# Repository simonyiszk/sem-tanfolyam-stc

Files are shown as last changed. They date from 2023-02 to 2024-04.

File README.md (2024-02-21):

# sem-tanfolyam-stc #

STC8G1K08 mikrovezérlős fejlesztőpanel a Schönherz Elektronikai Műhely alapozó tanfolyamához (2023-tól).
A projekt tartalmaz a devboardon kívül egy analóg hőmérővel, 7-szegmens kijelzőkkel, LED-ekkel, valamint gombokkal felszerelt alappanelt is, ezt tervezzük meg és készítjük el a tanfolyam során.

### Fejlesztőpanel fícsörök: ###
* Breadboard-ba illeszthető
* Feliratozott lábak
* USB-C csatlakozó
* Integrált programozó és táp-glitchelő áramkör
* Táp- és kommunikáció visszajelző LED-ek
* RESET gomb

[A mikrovezérlő adatlapja itt található.](https://www.stcmcudata.com/STC8F-DATASHEET/STC8G-EN.pdf)

tanfolyam-stc

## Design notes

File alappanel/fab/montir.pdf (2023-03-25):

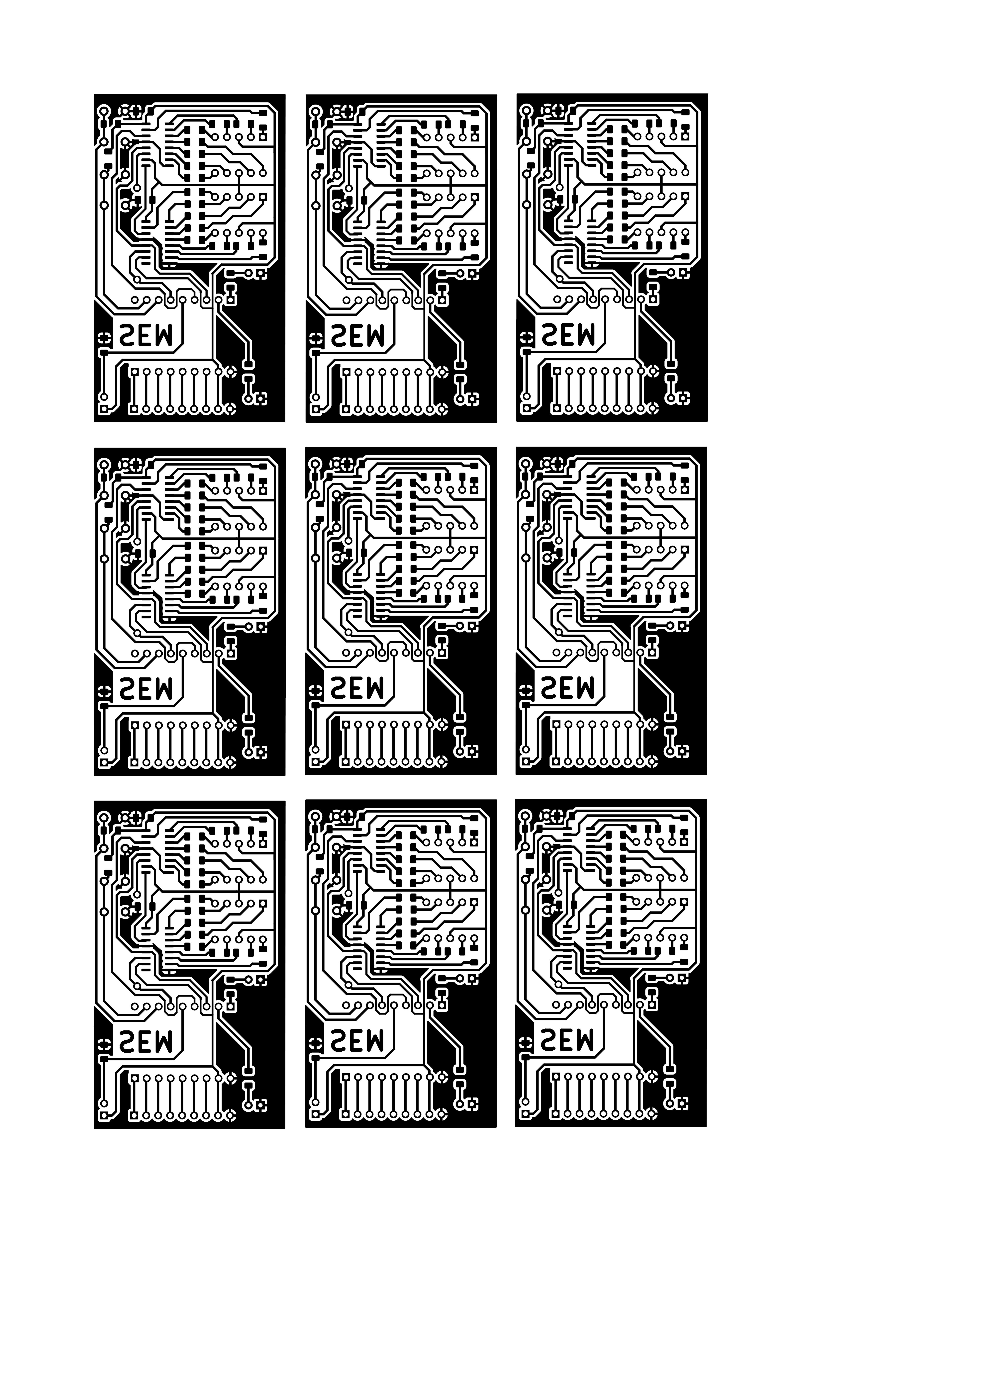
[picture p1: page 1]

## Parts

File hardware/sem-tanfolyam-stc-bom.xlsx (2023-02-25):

Comment | Designator | Footprint | JLCPCB Part #（optional）
100nF | C1, C3 | Capacitor_SMD:C_0603_1608Metric | C14663
1uF | C2, C4 | Capacitor_SMD:C_0603_1608Metric | C15849
LL4148 | D1, D2 | Diode_SMD:D_MiniMELF | C9808
Red | D3 | LED_SMD:LED_0603_1608Metric | C2286
Yellow | D4 | LED_SMD:LED_0603_1608Metric | C72038
1A | F1 | Fuse:Fuse_1206_3216Metric | C883131
Conn_01x09_Male | J1, J2 | Connector_PinHeader_2.54mm:PinHeader_1x09_P2.54mm_Vertical
USB_C_Receptacle_USB2.0 | J3 | Connector_USB:USB_C_Receptacle_G-Switch_GT-USB-7010ASV | C2765186
MMBT5401 | Q1 | Package_TO_SOT_SMD:SOT-23 | C8326
AO3401 | Q2 | Package_TO_SOT_SMD:SOT-23 | C15127
220 | R1, R6 | Resistor_SMD:R_0603_1608Metric | C8218
10k | R2, R3, R4, R5, R7 | Resistor_SMD:R_0603_1608Metric | C25804
5k1 | R8, R9 | Resistor_SMD:R_0603_1608Metric | C23186
1k | R10, R11 | Resistor_SMD:R_0603_1608Metric | C21190
SW_Push | SW1 | Button_Switch_SMD:SW_Push_1P1T_NO_6x6mm_H9.5mm | C318884
CH340E | U1 | Package_SO:MSOP-10_3x3mm_P0.5mm | C99652
STC8G1K08 | U2 | Package_SO:TSSOP-20_4.4x6.5mm_P0.65mm | C521757

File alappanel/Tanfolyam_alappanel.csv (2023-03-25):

Source: | /home/pali/Documents/BME/SEM/Tanfolyam/Tanfolyam-STC/alappanel/Tanfolyam_alappanel.kicad_sch
Date: | 2023. márc. 25., szombat, 10:59:26 CET
Tool: | Eeschema 7.0.1-3b83917a11~172~ubuntu22.04.1
Generator: | /usr/share/kicad/plugins/bom_csv_grouped_by_value.py
Component Count: | 35
Collated Components:
Item | Qty | Reference(s) | Value | LibPart | Footprint | Datasheet | DNP
1 | 2 | C1, C2 | 100n | Device:C | Capacitor_SMD:C_1206_3216Metric_Pad1.33x1.80mm_HandSolder | ~
2 | 2 | D1, D2 | RED | Device:LED_Filled | LED_THT:LED_D5.0mm | ~
3 | 2 | J1, J2 | Connector | Connector:Conn_01x09_Socket | Connector_PinSocket_2.54mm:PinSocket_1x09_P2.54mm_Vertical | ~
4 | 1 | J3 | Connector | Connector:Conn_01x09_Socket | Connector_PinHeader_2.54mm:PinHeader_1x09_P2.54mm_Vertical | ~
5 | 1 | R1 | R | Device:R | Resistor_SMD:R_1206_3216Metric_Pad1.30x1.75mm_HandSolder | ~
6 | 2 | R2, R3 | 10k | Device:R | Resistor_SMD:R_1206_3216Metric_Pad1.30x1.75mm_HandSolder | ~
7 | 18 | R4, R5, R6, R7, R8, R9, R10, R11, R12, R13, R14, R15, R16, R17, R18, R19, R20, R21 | 1k | Device:R | Resistor_SMD:R_1206_3216Metric_Pad1.30x1.75mm_HandSolder | ~
8 | 2 | SW1, SW2 | SW_Push | Switch:SW_Push | Button_Switch_THT:SW_PUSH_6mm | ~
9 | 1 | TH1 | NTC | Device:Thermistor | Connector_PinHeader_2.54mm:PinHeader_1x02_P2.54mm_Vertical | ~
10 | 2 | U1, U2 | 74HC595 | 74xx:74HC595 | Package_SO:SOIC-16_3.9x9.9mm_P1.27mm | http://www.ti.com/lit/ds/symlink/sn74hc595.pdf
11 | 2 | U3, U4 | SA39-11SRWA | Display_Character:SA39-11SRWA | Display_7Segment:Sx39-1xxxxx | http://www.kingbrightusa.com/images/catalog/SPEC/sa39-11srwa.pdf

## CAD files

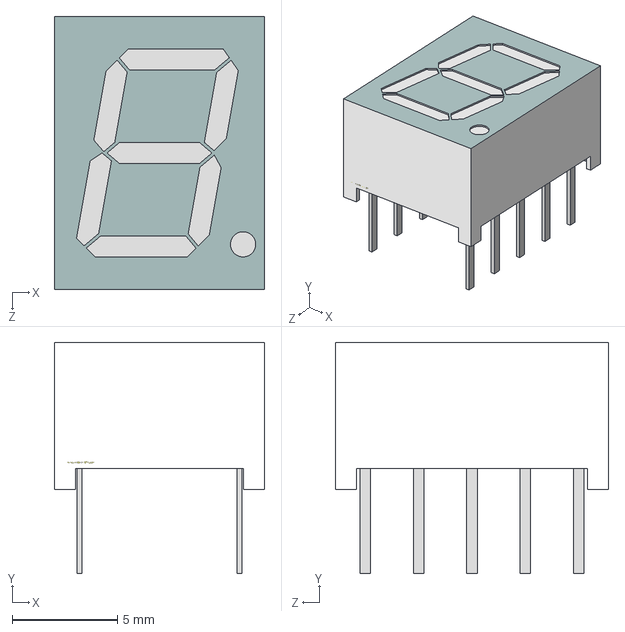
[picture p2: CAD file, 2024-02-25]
alappanel/SA39-11.STEP
10.0 x 11.0 x 13.0 mm

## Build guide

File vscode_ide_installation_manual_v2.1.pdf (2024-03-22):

## Visual Studio Code-alapú fejlesztői környezet telepítési útmutatója a

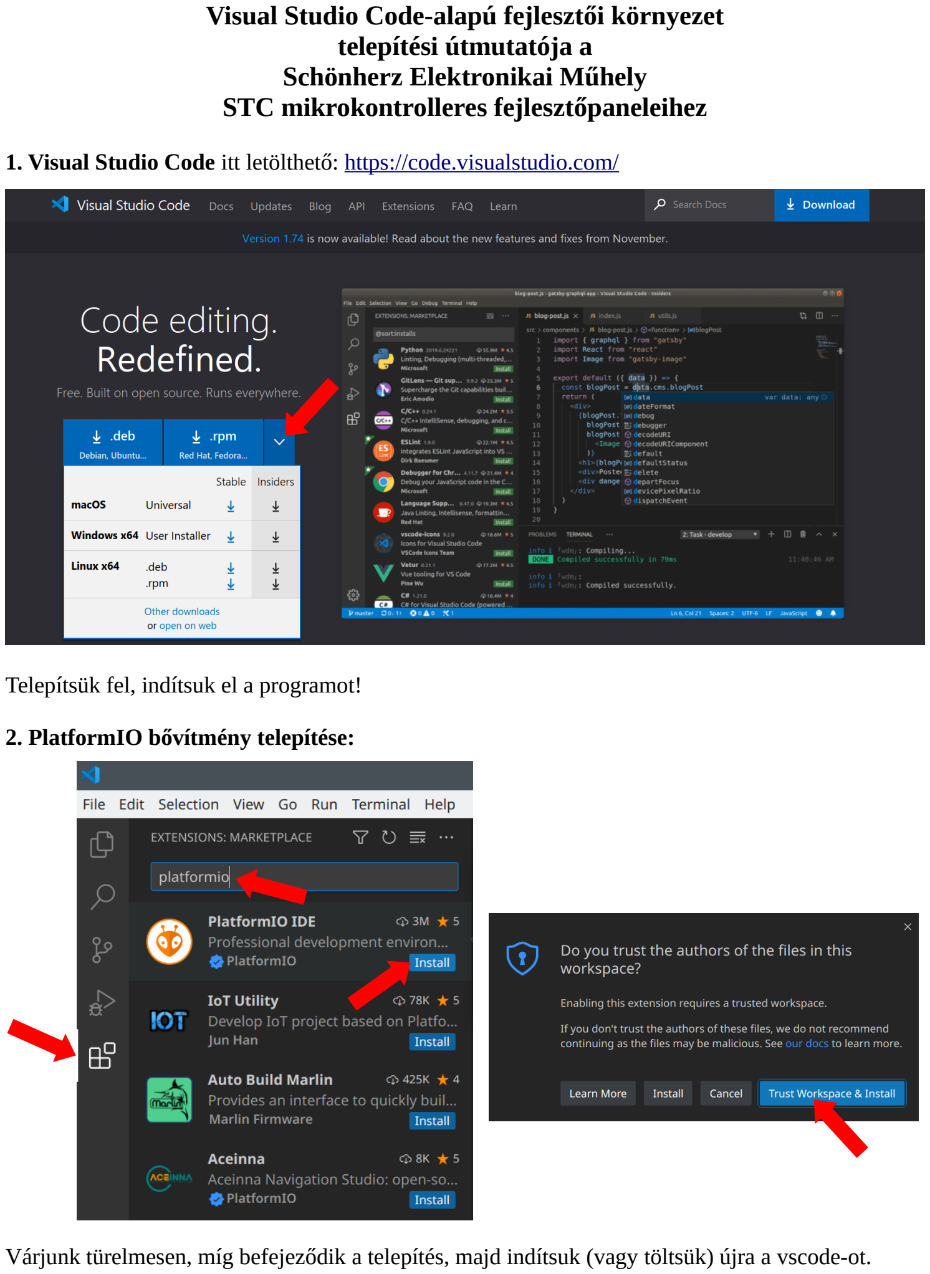
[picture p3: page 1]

## Schönherz Elektronikai Műhely STC mikrokontrolleres fejlesztőpaneleihez

### 1. Visual Studio Code itt letölthető: https://code.visualstudio.com/

Telepítsük fel, indítsuk el a programot!

## 2. PlatformIO bővítmény telepítése:

Várjunk türelmesen, míg befejeződik a telepítés, majd indítsuk (vagy töltsük) újra a vscode-ot.

## 3. Hozzunk létre egy új projektet!

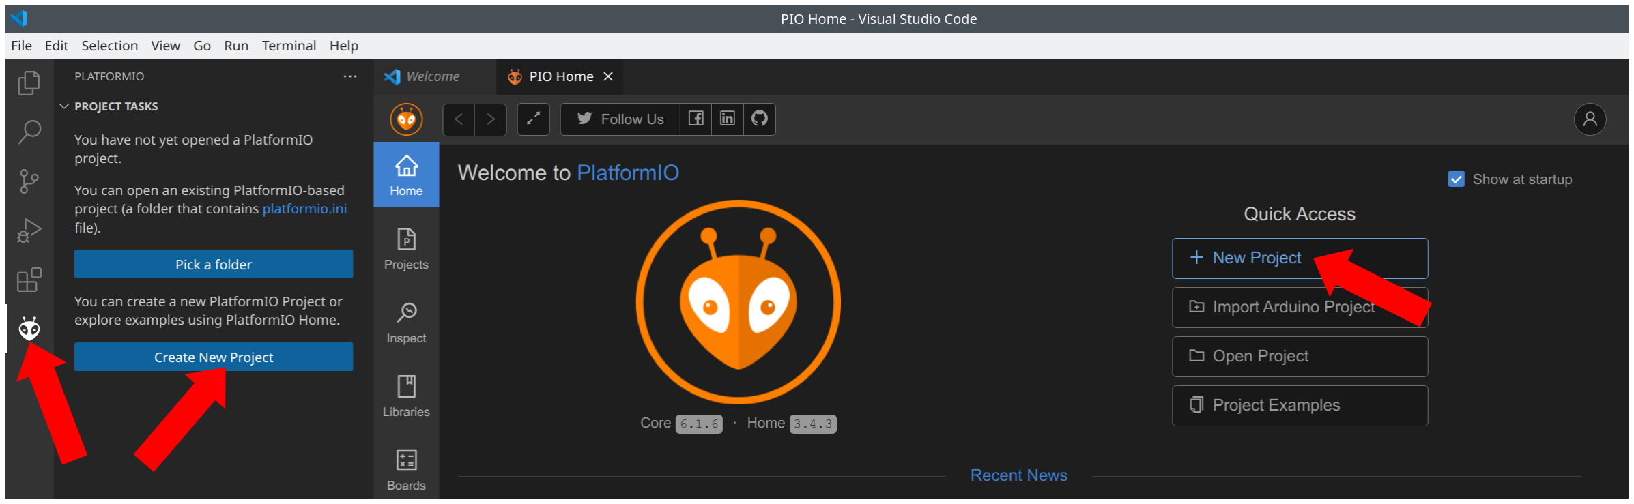
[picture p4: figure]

Adjunk nevet a projektnek! A Board legyen a mikrokontroller típusának megfelelően
Generic STC8G1K08, a projektfájlok helye tetszőleges lehet. A Framework mezőt hagyjuk üresen.

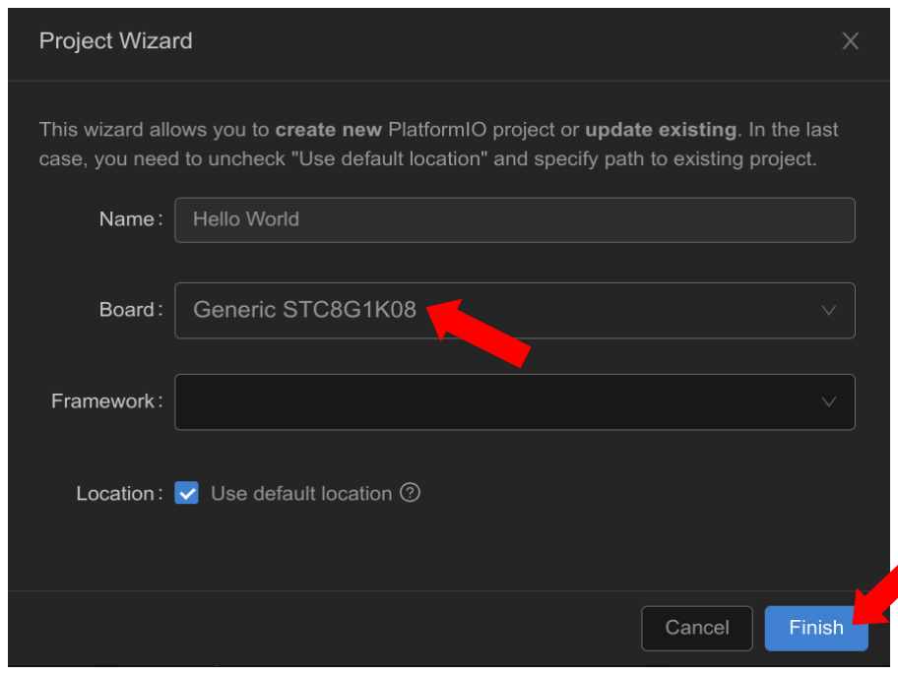
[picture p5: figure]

Ha kérdezi a program,

## 4. A platformio.ini fájl tartalmát cseréljük le erre:

[env:STC8G1K08]
platform = intel_mcs51
board = STC8G1K08
board_build.mcu = STC8G1K08 board_build.f_cpu = 12000000 build_flags =
-D__CONF_FOSC=12000000UL
-D__CONF_MCU_MODEL=MCU_MODEL_STC8G1K08 -D__CONF_CLKDIV=0x01
upload_protocol = stcgal
upload_flags =
-t12000
-Pstc8g
-oreset_pin_enabled=True
upload_command = stcgal $UPLOAD_FLAGS $SOURCE

## Így lehet konfigurálni a programozót. Fontos odafigyelni a szóközökre, behúzásokra!

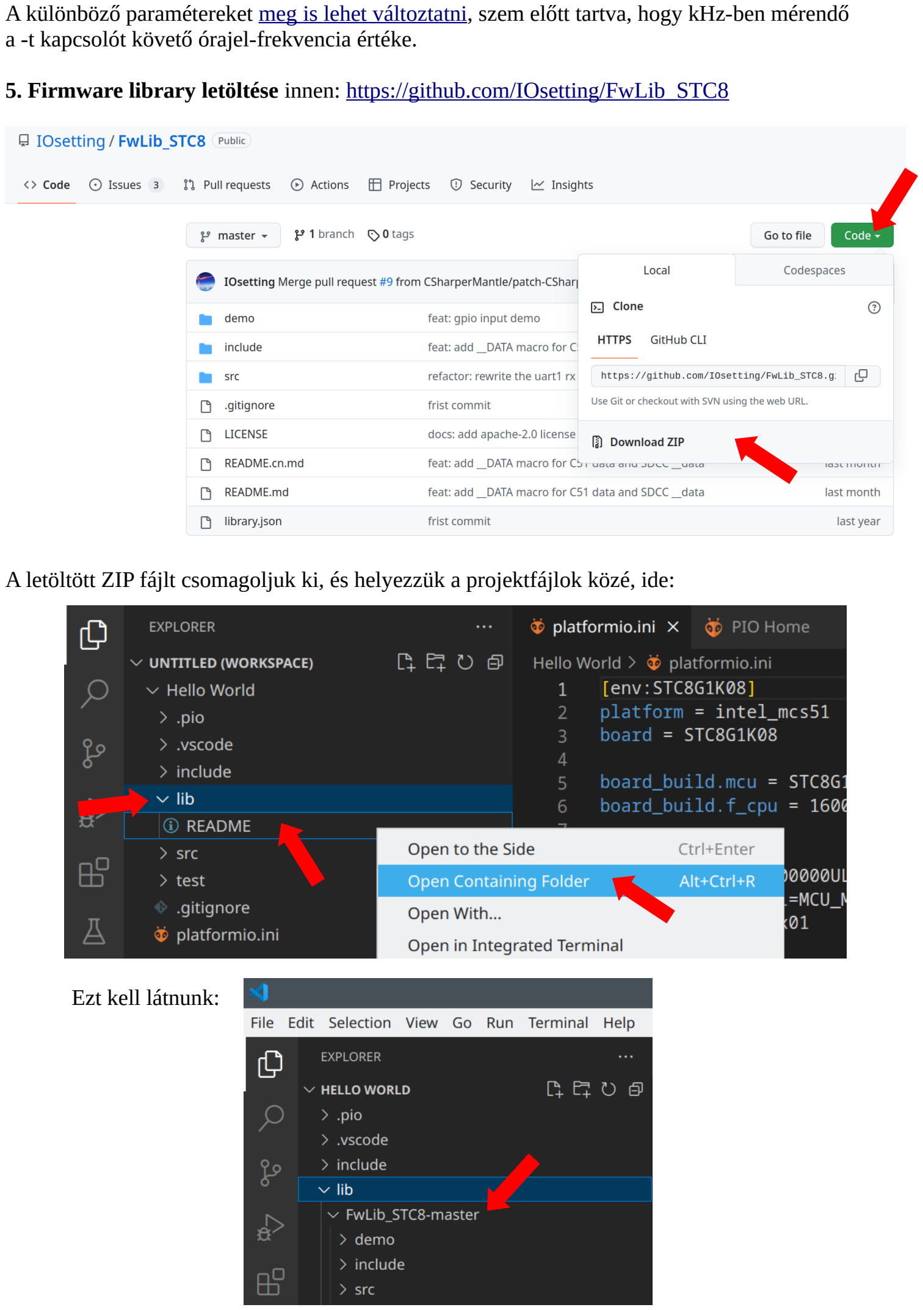
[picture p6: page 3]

A különböző paramétereket meg (https://github.com/area-8051/stcgal-patched/blob/master/doc/USAGE.md) is (https://github.com/area-8051/stcgal-patched/blob/master/doc/USAGE.md) lehet változtatni, (https://github.com/area-8051/stcgal-patched/blob/master/doc/USAGE.md) szem előtt tartva, hogy kHz-ben mérendő a -t kapcsolót követő órajel-frekvencia értéke.

### 5. Firmware library letöltése innen: https://github.com/IOsetting/FwLib_STC8

A letöltött ZIP fájlt csomagoljuk ki, és helyezzük a projektfájlok közé, ide:

Ezt kell látnunk:

## 6. Programírás

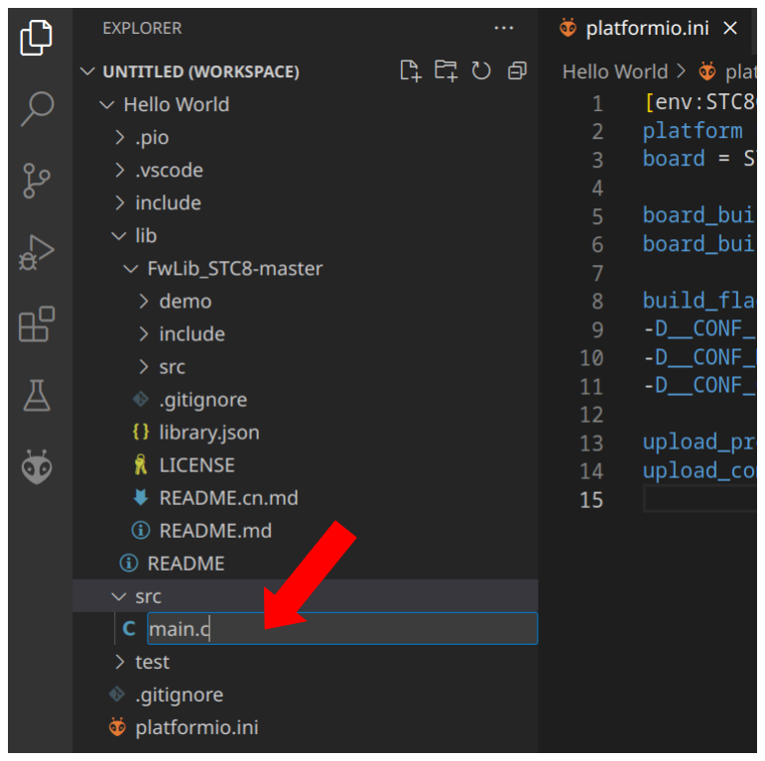
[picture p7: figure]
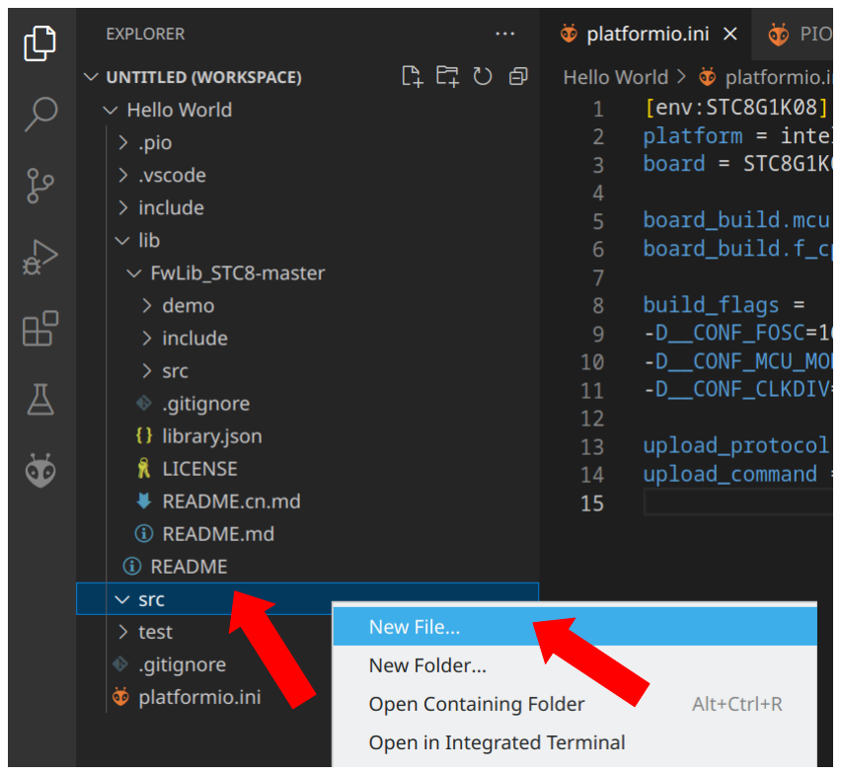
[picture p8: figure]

Ez a kis program például a fejlesztőpanel P1.0 jelű lábára kapcsolt LED-ed fogja villogtatni.

#include "fw_hal.h"

int main(void)
{

GPIO_P1_SetMode(GPIO_Pin_0, GPIO_Mode_Output_PP);

P10 = RESET;

while(1)
{
SYS_Delay(500);

P10 = !P10;
}
}

(Ha megépítjük az áramkört, ne felejtsünk el megfelelően méretezett előtét-ellenállást sorosan kapcsolni a LED-del! A hőmérős alappanel használata esetén erre nincs szükség.)

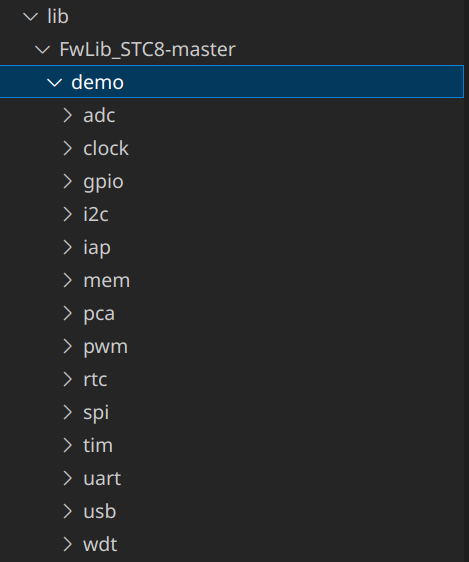
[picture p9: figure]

További érdekes példakódokat italálhatunk a demo mappában:

## 7. Fordítás:

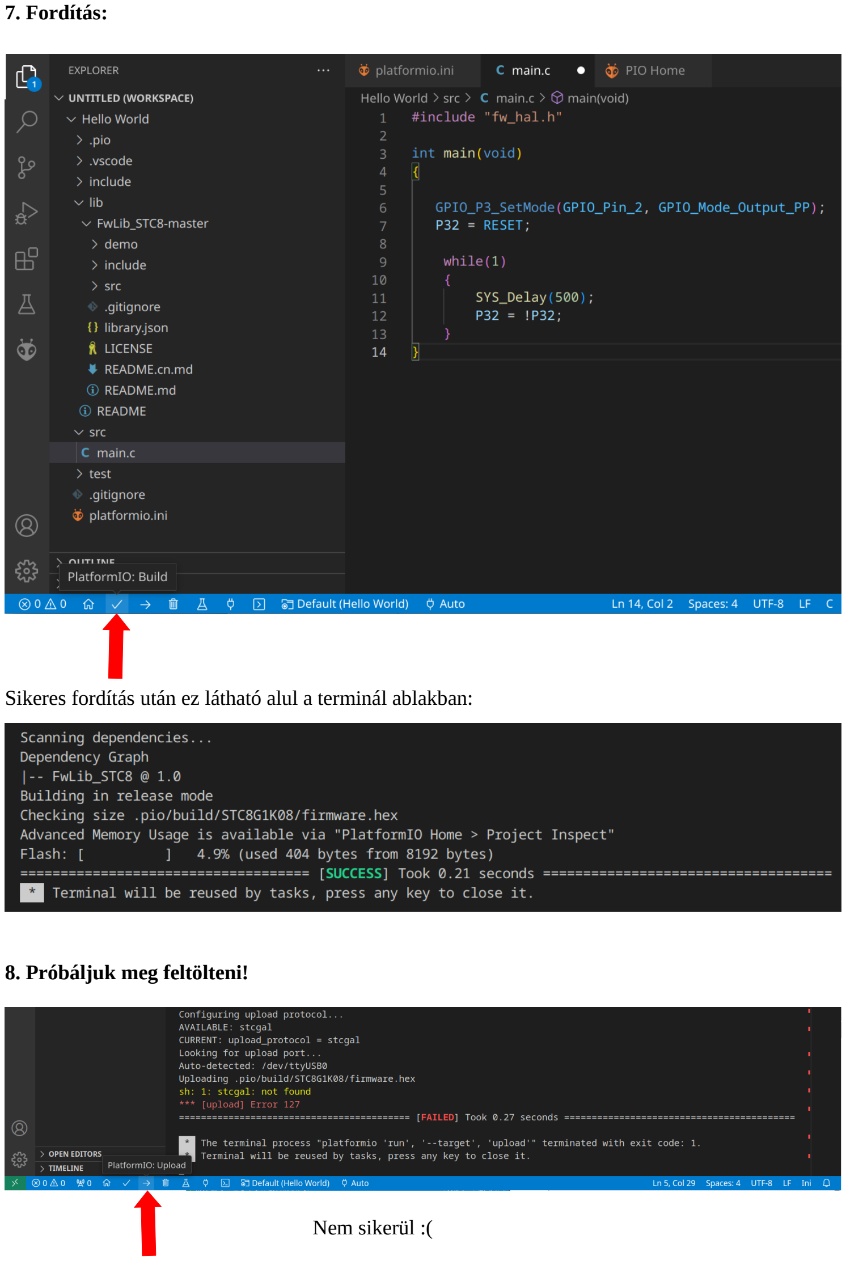
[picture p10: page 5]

Sikeres fordítás után ez látható alul a terminál ablakban:

## 8. Próbáljuk meg feltölteni!

Nem sikerül :(

## 9. Utolsó simítások

Telepítsük a programozó szoftver megfelelő verzióját az itteni leírások alapján:

https://github.com/grigorig/stcgal/blob/master/doc/INSTALL.md

Vagy írjuk be parancssorba/terminálba a következőt:

pip3 install stcgal

(Python3, pip3 előzetes feltelepítése és rendszergazdai jogosultság fog kelleni hozzá.)

Ezt követően simán működnie kell a program feltöltésének is.

Jó étvágyat :)

A leírást aktualizálta a tavalyi alapján: Weisz Pál, 2024. március

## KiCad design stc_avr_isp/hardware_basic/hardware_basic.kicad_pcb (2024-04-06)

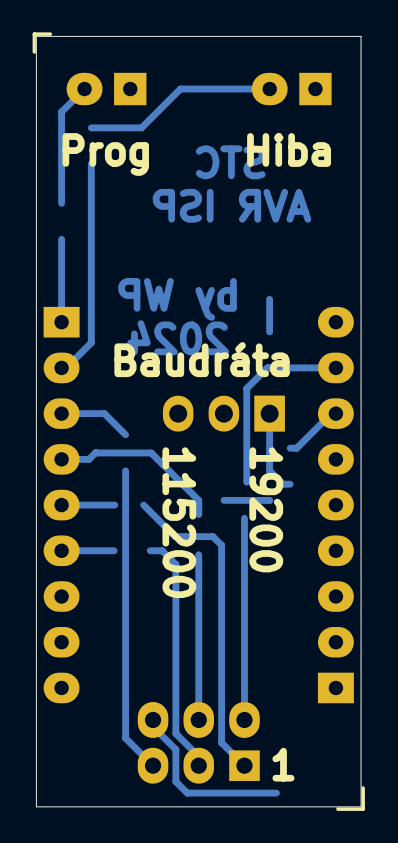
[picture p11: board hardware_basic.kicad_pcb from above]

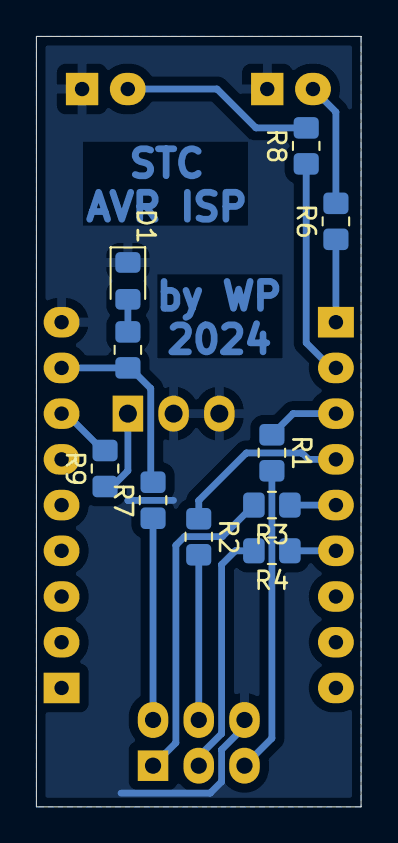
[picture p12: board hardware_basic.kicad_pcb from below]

Board: 2 copper layers, 18.0 x 42.8 mm, 16 parts (10 on the bottom side), 18 nets.

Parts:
D1: LED_Filled; LED_0805_2012Metric_Pad1.15x1.40mm_HandSolder
D2: PROG; LED_D3.0mm
D3: ERROR; LED_D3.0mm
J1, J2: Conn_01x09_Socket; PinSocket_1x09_P2.54mm_Vertical
J3: ISP; PinSocket_2x03_P2.54mm_Horizontal
J4: BAUD RATE; PinHeader_1x03_P2.54mm_Vertical
R1, R2, R3, R4: 100; R_0805_2012Metric_Pad1.20x1.40mm_HandSolder
R5, R6, R8, R9: 330; R_0805_2012Metric_Pad1.20x1.40mm_HandSolder
R7: 0; R_0805_2012Metric_Pad1.20x1.40mm_HandSolder

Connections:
+5V: J2.8, R5.1, R7.2
/MISO: J3.6, R3.2
/MOSI: J3.3, R2.2
/P1.0: J1.1, R6.1
/P1.1: J1.2, R8.1
/P5.5: J2.7, R9.2
/RESET: J3.2, R1.2
/SCLK: J3.4, R4.2
GND: D1.1 (K), D2.1 (K), D3.1 (K), J2.9, J3.1, J4.2, J4.3
unnamed: D1.2 (A), R5.2
unnamed: D2.2 (A), R6.2
unnamed: D3.2 (A), R8.2
unnamed: J1.3, R1.1
unnamed: J1.4, R2.1
unnamed: J1.5, R3.1
unnamed: J1.6, R4.1
unnamed: J3.5, R7.1
unnamed: J4.1, R9.1

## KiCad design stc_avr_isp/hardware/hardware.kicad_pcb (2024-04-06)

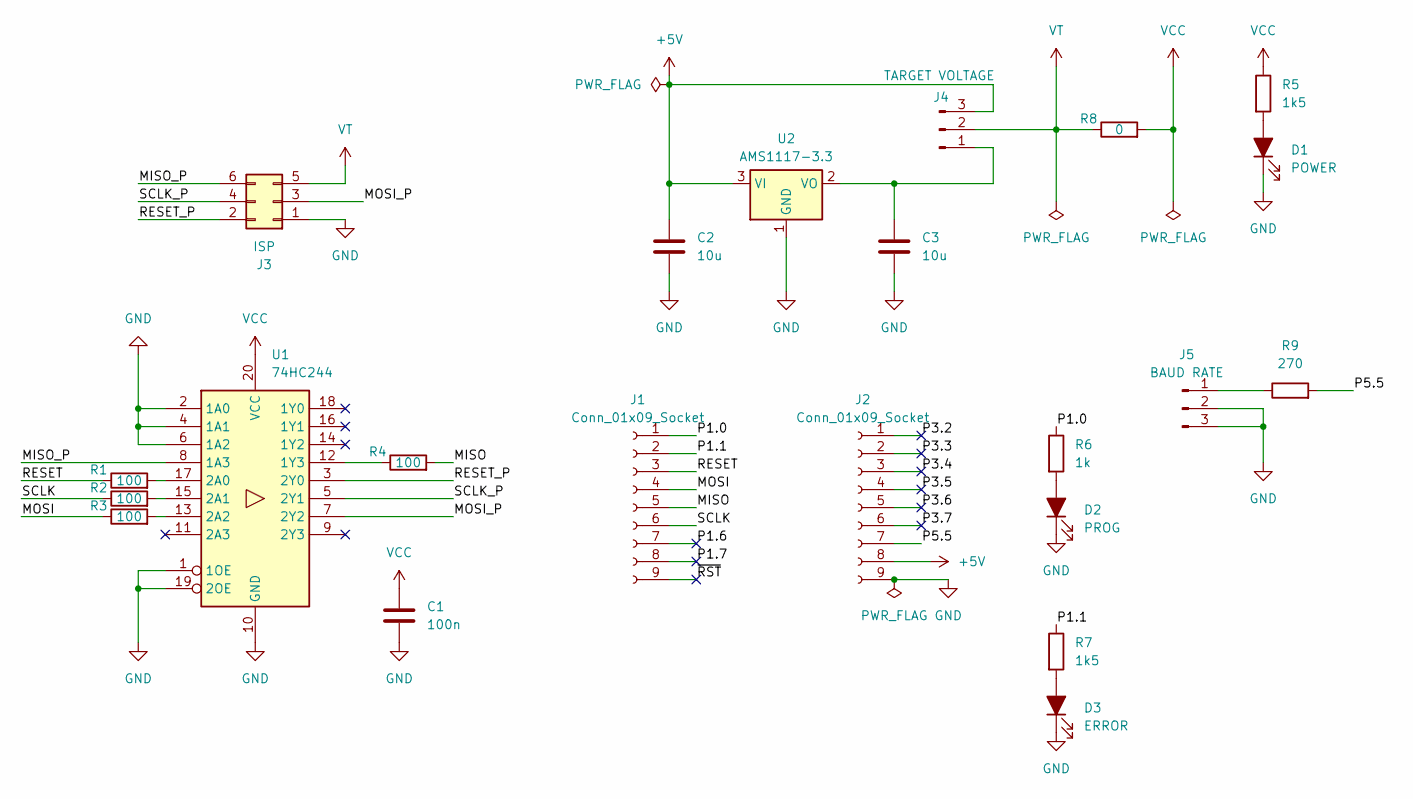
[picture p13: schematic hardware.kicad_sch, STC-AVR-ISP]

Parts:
C1: 100n; C_0805_2012Metric_Pad1.18x1.45mm_HandSolder
C2, C3: 10u; C_0805_2012Metric_Pad1.18x1.45mm_HandSolder
D1: POWER; LED_0805_2012Metric_Pad1.15x1.40mm_HandSolder
D2: PROG; LED_D3.0mm
D3: ERROR; LED_D3.0mm
J1, J2: Conn_01x09_Socket; PinSocket_1x09_P2.54mm_Vertical
J3: ISP; PinSocket_2x03_P2.54mm_Horizontal
J4: TARGET VOLTAGE; PinHeader_1x03_P2.54mm_Vertical
J5: BAUD RATE; PinHeader_1x03_P2.54mm_Vertical
R1, R2, R3, R4: 100; R_0805_2012Metric_Pad1.20x1.40mm_HandSolder
R5, R7: 1k5; R_0805_2012Metric_Pad1.20x1.40mm_HandSolder
R6: 1k; R_0805_2012Metric_Pad1.20x1.40mm_HandSolder
R8: 0; R_0805_2012Metric_Pad1.20x1.40mm_HandSolder
R9: 270; R_0805_2012Metric_Pad1.20x1.40mm_HandSolder
U1: 74HC244; TSSOP-20_4.4x6.5mm_P0.65mm
U2: AMS1117-3.3; SOT-223-3_TabPin2

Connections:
+5V: C2.1, J2.8, J4.3, U2.3 (VI)
/MISO: J1.5, R4.2
/MISO_P: J3.6, U1.8 (1A3)
/MOSI: J1.4, R3.1
/MOSI_P: J3.3, U1.7 (2Y2)
/P1.0: J1.1, R6.1
/P1.1: J1.2, R7.1
/P1.6: J1.7
/P1.7: J1.8
/P3.2: J2.1
/P3.3: J2.2
/P3.4: J2.3
/P3.5: J2.4
/P3.6: J2.5
/P3.7: J2.6
/P5.5: J2.7, R9.2
/RESET: J1.3, R1.1
/RESET_P: J3.2, U1.3 (2Y0)
/SCLK: J1.6, R2.1
/SCLK_P: J3.4, U1.5 (2Y1)
/~RST: J1.9
GND: C1.2, C2.2, C3.2, D1.1 (K), D2.1 (K), D3.1 (K), J2.9, J3.1, J5.2, J5.3, U1.1 (1OE), U1.2 (1A0), U1.4 (1A1), U1.6 (1A2), U1.10 (GND), U1.19 (2OE), U2.1 (GND)
unnamed: D1.2 (A), R5.2
unnamed: D2.2 (A), R6.2
unnamed: D3.2 (A), R7.2
unnamed: C3.1, J4.1, U2.2 (VO)
unnamed: J5.1, R9.1
unnamed: R4.1, U1.12 (1Y3)
unnamed: R1.2, U1.17 (2A0)
unnamed: R2.2, U1.15 (2A1)
unnamed: R3.2, U1.13 (2A2)
VCC: C1.1, R5.1, R8.2, U1.20 (VCC)
VT: J3.5, J4.2, R8.1

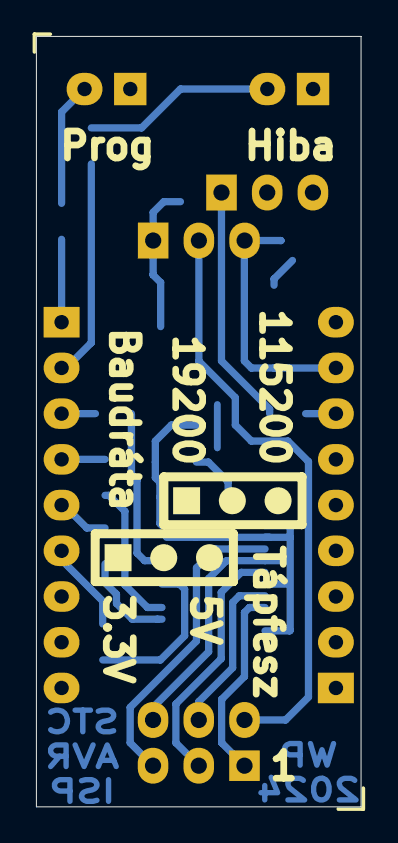
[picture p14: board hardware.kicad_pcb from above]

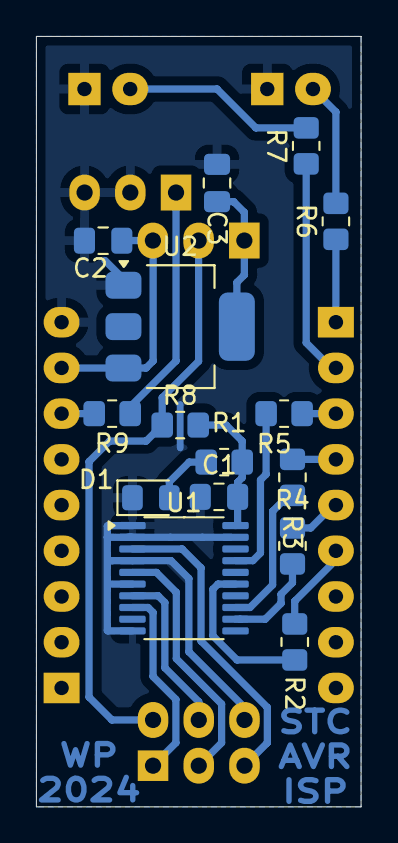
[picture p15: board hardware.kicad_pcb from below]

Board: 2 copper layers, 18.0 x 42.8 mm, 22 parts (15 on the bottom side), 24 nets.

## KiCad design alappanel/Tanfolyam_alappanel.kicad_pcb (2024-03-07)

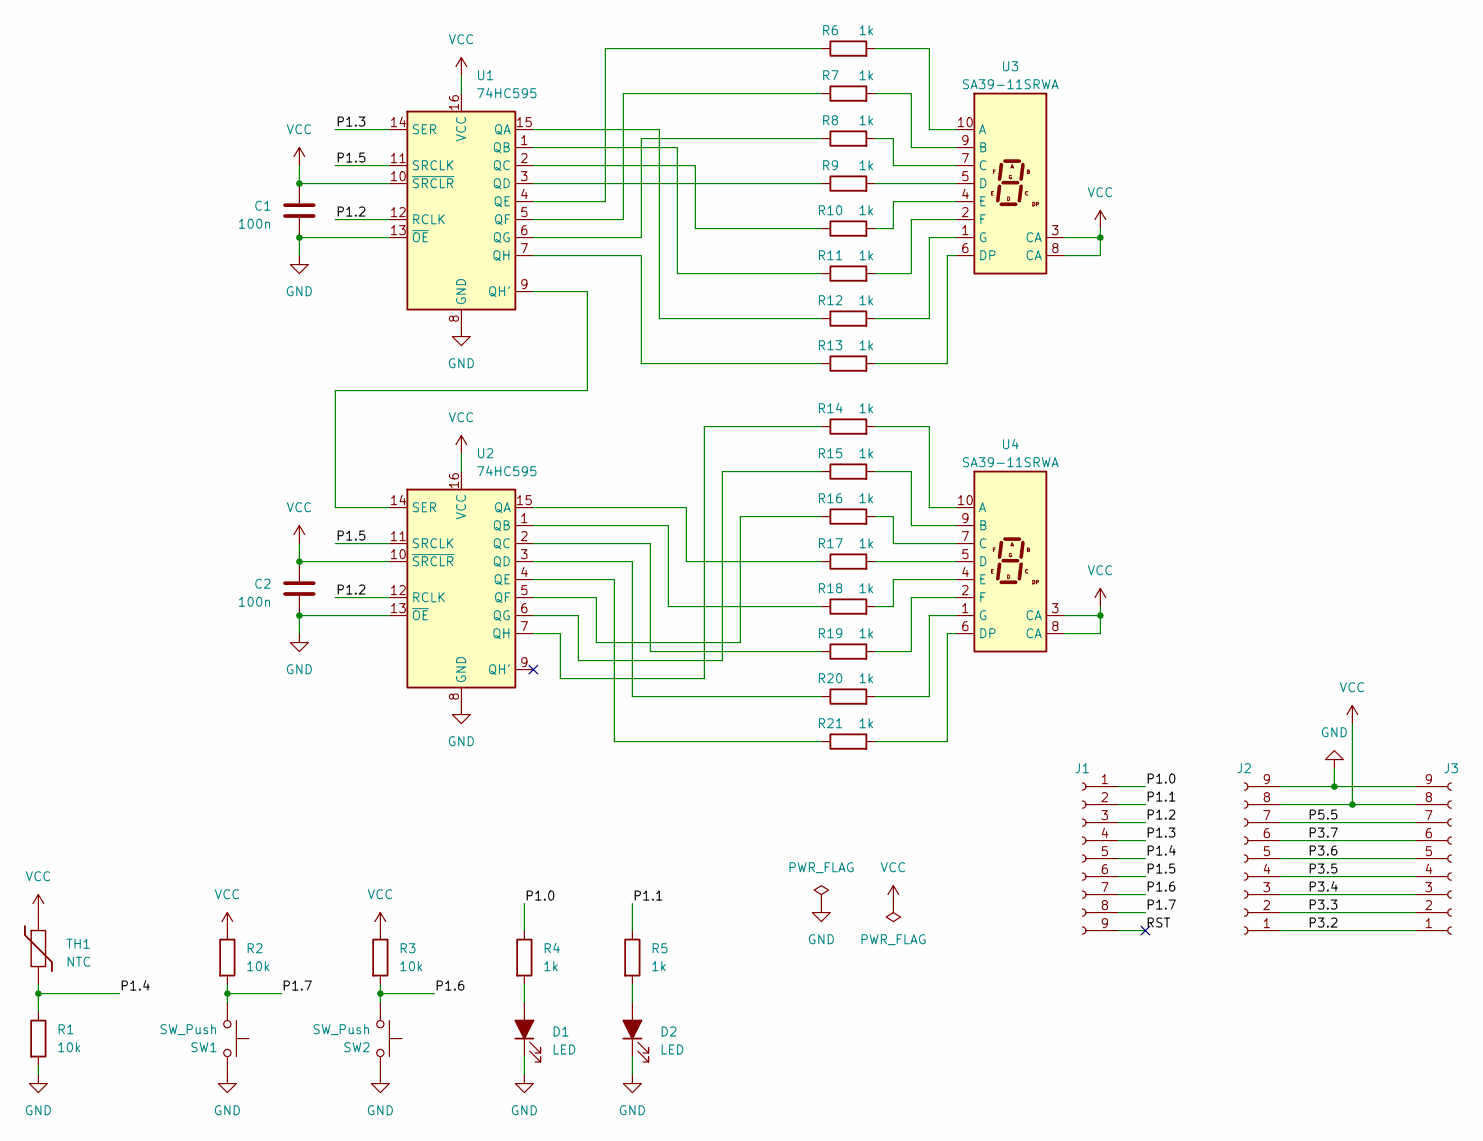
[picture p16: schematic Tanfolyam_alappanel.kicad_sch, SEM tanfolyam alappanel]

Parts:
C1, C2: 100n; C_1206_3216Metric_Pad1.33x1.80mm_HandSolder
D1, D2: LED; LED_D5.0mm
J1, J2: Connector; PinSocket_1x09_P2.54mm_Vertical
J3: Connector; PinHeader_1x09_P2.54mm_Vertical
R1, R2, R3: 10k; R_1206_3216Metric_Pad1.30x1.75mm_HandSolder
R4, R5, R6, R7, R8, R9, R10, R11, R12, R13, R14, R15, R16, R17, R18, R19, R20, R21: 1k; R_1206_3216Metric_Pad1.30x1.75mm_HandSolder
SW1, SW2: SW_Push; SW_PUSH_6mm
TH1: NTC; PinHeader_1x02_P2.54mm_Vertical
U1, U2: 74HC595; SOIC-16_3.9x9.9mm_P1.27mm
U3, U4: SA39-11SRWA; Sx39-1xxxxx

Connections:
/P1.0: J1.1, R4.1
/P1.1: J1.2, R5.1
/P1.2: J1.3, U1.12 (RCLK), U2.12 (RCLK)
/P1.3: J1.4, U1.14 (SER)
/P1.4: J1.5, R1.1, TH1.2
/P1.5: J1.6, U1.11 (SRCLK), U2.11 (SRCLK)
/P1.6: J1.7, R3.2, SW2.1
/P1.7: J1.8, R2.2, SW1.1
/P3.2: J2.1, J3.1
/P3.3: J2.2, J3.2
/P3.4: J2.3, J3.3
/P3.5: J2.4, J3.4
/P3.6: J2.5, J3.5
/P3.7: J2.6, J3.6
/P5.5: J2.7, J3.7
/RST: J1.9
GND: C1.2, C2.2, D1.1 (K), D2.1 (K), J2.9, J3.9, R1.2, SW1.2, SW2.2, U1.8 (GND), U1.13 (~OE), U2.8 (GND), U2.13 (~OE)
unnamed: D1.2 (A), R4.2
unnamed: D2.2 (A), R5.2
unnamed: R12.1, U1.15 (QA)
unnamed: R11.1, U1.1 (QB)
unnamed: R10.1, U1.2 (QC)
unnamed: R9.1, U1.3 (QD)
unnamed: R6.1, U1.4 (QE)
unnamed: R7.1, U1.5 (QF)
unnamed: R8.1, U1.6 (QG)
unnamed: U1.9 (QH'), U2.14 (SER)
unnamed: R13.1, U1.7 (QH)
unnamed: R17.1, U2.15 (QA)
unnamed: R18.1, U2.1 (QB)
unnamed: R19.1, U2.2 (QC)
unnamed: R20.1, U2.3 (QD)
unnamed: R21.1, U2.4 (QE)
unnamed: R16.1, U2.5 (QF)
unnamed: R15.1, U2.6 (QG)
unnamed: R14.1, U2.7 (QH)
unnamed: R6.2, U3.10 (A)
unnamed: R7.2, U3.9 (B)
unnamed: R8.2, U3.7 (C)
unnamed: R9.2, U3.5 (D)
unnamed: R13.2, U3.6 (DP)
unnamed: R10.2, U3.4 (E)
unnamed: R11.2, U3.2 (F)
unnamed: R12.2, U3.1 (G)
unnamed: R14.2, U4.10 (A)
unnamed: R15.2, U4.9 (B)
unnamed: R16.2, U4.7 (C)
unnamed: R17.2, U4.5 (D)
unnamed: R21.2, U4.6 (DP)
unnamed: R18.2, U4.4 (E)
unnamed: R19.2, U4.2 (F)
unnamed: R20.2, U4.1 (G)
VCC: C1.1, C2.1, J2.8, J3.8, R2.1, R3.1, TH1.1, U1.10 (~SRCLR), U1.16 (VCC), U2.10 (~SRCLR), U2.16 (VCC), U3.3 (CA), U3.8 (CA), U4.3 (CA), U4.8 (CA)

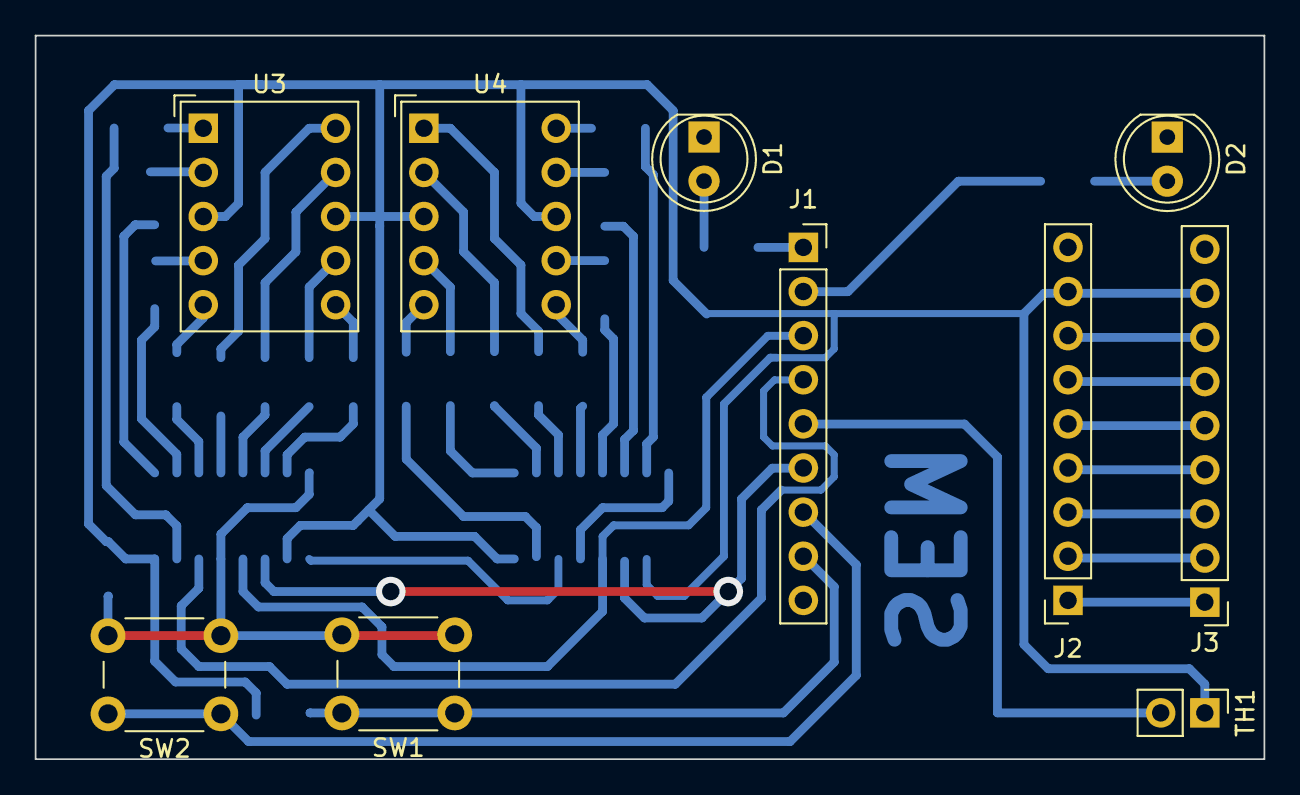
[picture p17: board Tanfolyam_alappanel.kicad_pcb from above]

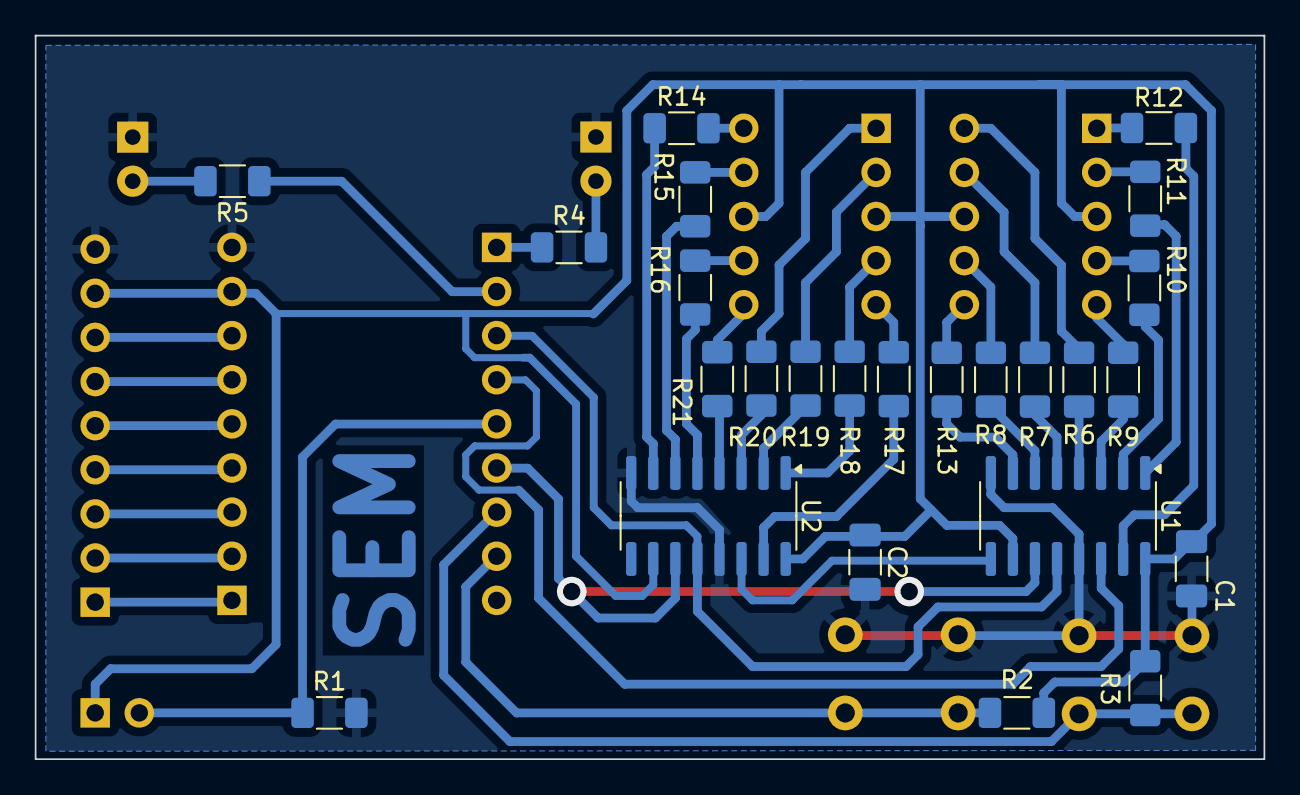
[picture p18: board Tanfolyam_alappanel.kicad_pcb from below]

Board: 2 copper layers, 70.7 x 41.7 mm, 35 parts (25 on the bottom side), 52 nets.

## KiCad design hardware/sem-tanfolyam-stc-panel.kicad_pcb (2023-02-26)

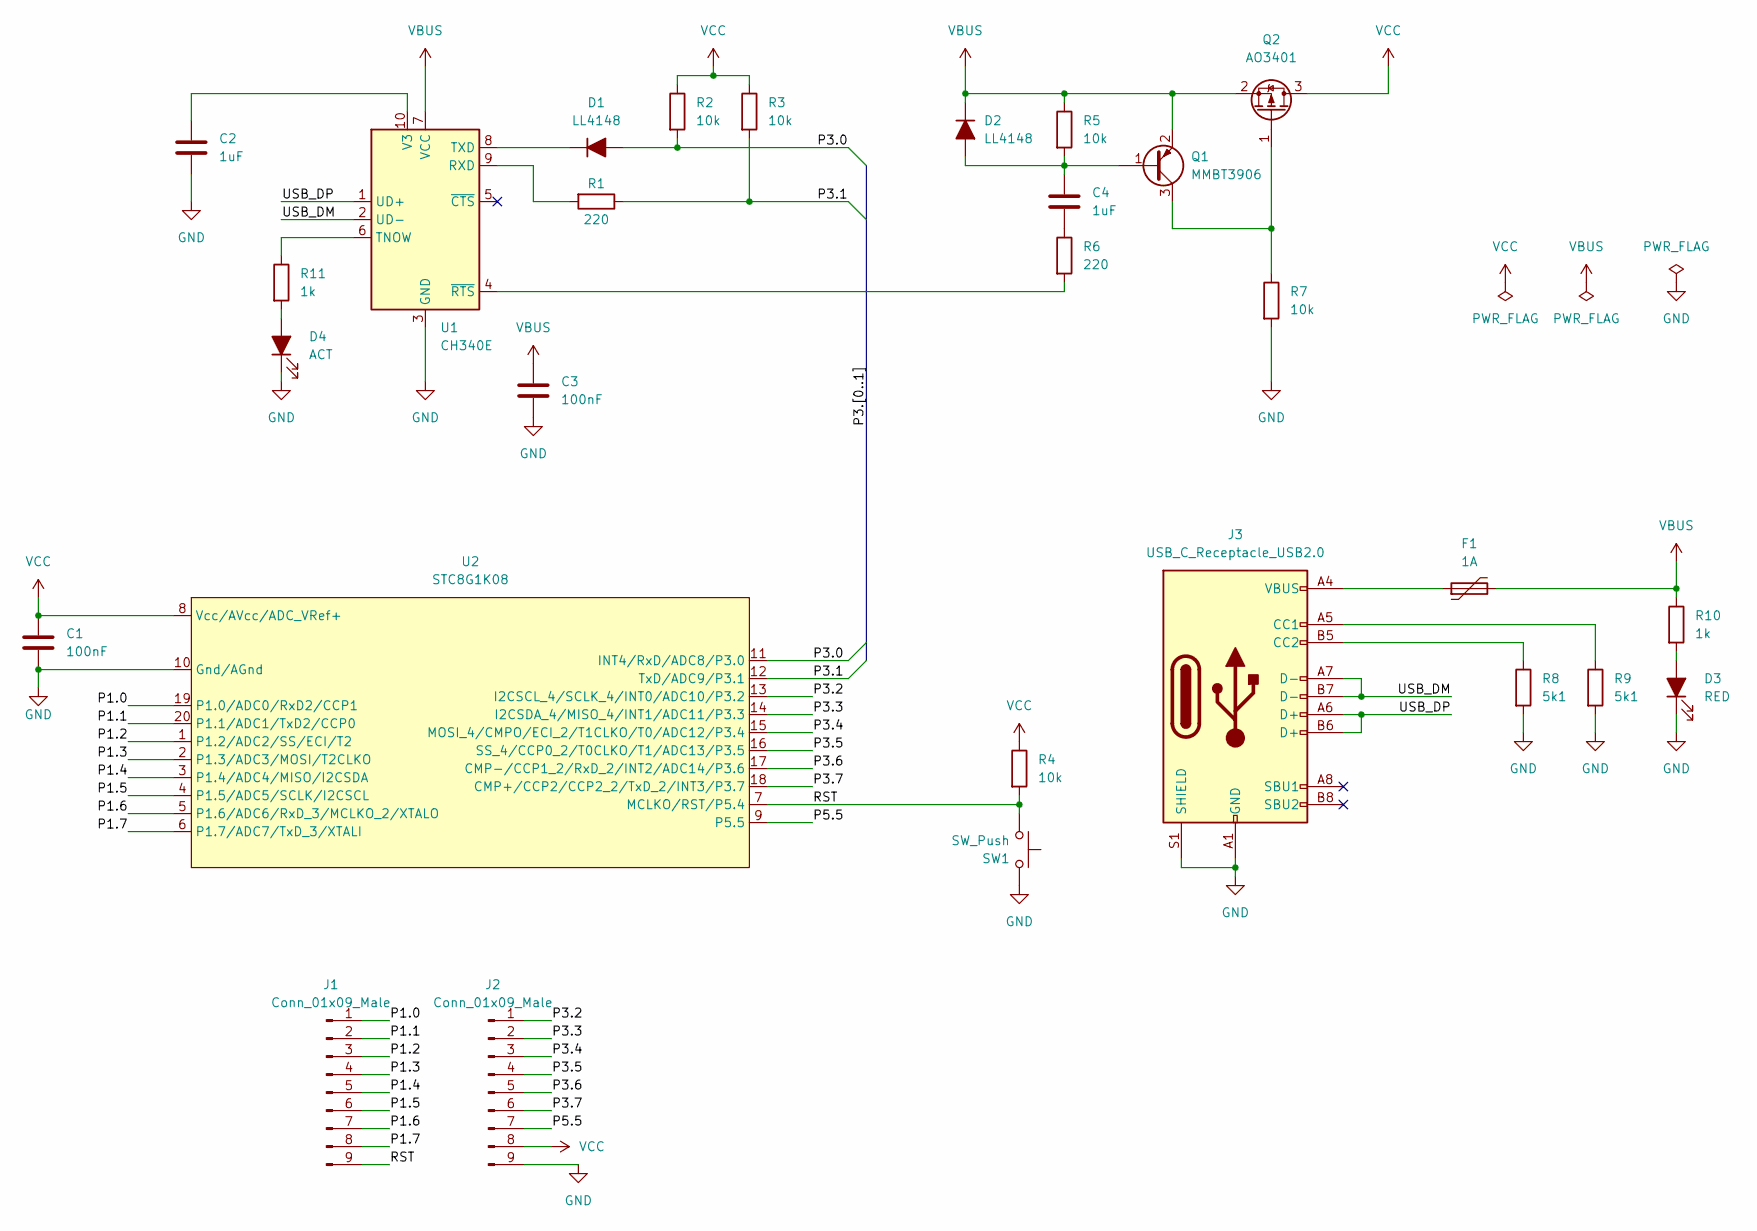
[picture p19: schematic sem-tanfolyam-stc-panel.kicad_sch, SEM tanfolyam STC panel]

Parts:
C1, C3: 100nF; C_0603_1608Metric
C2, C4: 1uF; C_0603_1608Metric
D1, D2: LL4148; D_MiniMELF
D3: RED; LED_0603_1608Metric
D4: ACT; LED_0603_1608Metric
F1: 1A; Fuse_1206_3216Metric
J1, J2: Conn_01x09_Male; PinHeader_1x09_P2.54mm_Vertical
J3: USB_C_Receptacle_USB2.0; USB_C_Receptacle_G-Switch_GT-USB-7010ASV
Q1: MMBT3906; SOT-23
Q2: AO3401; SOT-23
R1, R6: 220; R_0603_1608Metric
R2, R3, R4, R5, R7: 10k; R_0603_1608Metric
R8, R9: 5k1; R_0603_1608Metric
R10, R11: 1k; R_0603_1608Metric
SW1: SW_Push; SW_SPST_TL3342
U1: CH340E; MSOP-10_3x3mm_P0.5mm
U2: STC8G1K08; TSSOP-20_4.4x6.5mm_P0.65mm

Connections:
/P1.0: J1.1, U2.19 (P1.0/ADC0/RxD2/CCP1)
/P1.1: J1.2, U2.20 (P1.1/ADC1/TxD2/CCP0)
/P1.2: J1.3, U2.1 (P1.2/ADC2/SS/ECI/T2)
/P1.3: J1.4, U2.2 (P1.3/ADC3/MOSI/T2CLKO)
/P1.4: J1.5, U2.3 (P1.4/ADC4/MISO/I2CSDA)
/P1.5: J1.6, U2.4 (P1.5/ADC5/SCLK/I2CSCL)
/P1.6: J1.7, U2.5 (P1.6/ADC6/RxD_3/MCLKO_2/XTALO)
/P1.7: J1.8, U2.6 (P1.7/ADC7/TxD_3/XTALI)
/P3.0: D1.2 (A), R2.2, U2.11 (INT4/RxD/ADC8/P3.0)
/P3.1: R1.1, R3.2, U2.12 (TxD/ADC9/P3.1)
/P3.2: J2.1, U2.13 (I2CSCL_4/SCLK_4/INT0/ADC10/P3.2)
/P3.3: J2.2, U2.14 (I2CSDA_4/MISO_4/INT1/ADC11/P3.3)
/P3.4: J2.3, U2.15 (MOSI_4/CMPO/ECI_2/T1CLKO/T0/ADC12/P3.4)
/P3.5: J2.4, U2.16 (SS_4/CCP0_2/T0CLKO/T1/ADC13/P3.5)
/P3.6: J2.5, U2.17 (CMP-/CCP1_2/RxD_2/INT2/ADC14/P3.6)
/P3.7: J2.6, U2.18 (CMP+/CCP2/CCP2_2/TxD_2/INT3/P3.7)
/P5.5: J2.7, U2.9 (P5.5)
/RST: J1.9, R4.2, SW1.1, U2.7 (MCLKO/RST/P5.4)
/USB_DM: J3.A7 (D-), J3.B7 (D-), U1.2 (UD-)
/USB_DP: J3.A6 (D+), J3.B6 (D+), U1.1 (UD+)
GND: C1.2, C2.2, C3.2, D3.1 (K), D4.1 (K), J2.9, J3.A1 (GND), J3.A12 (GND), J3.B1 (GND), J3.B12 (GND), J3.S1 (SHIELD), R7.2, R8.2, R9.2, SW1.2, U1.3 (GND), U2.10 (Gnd/AGnd)
unnamed: C4.2, R6.1
unnamed: D1.1 (K), U1.8 (TXD)
unnamed: C4.1, D2.2 (A), Q1.1 (B), R5.2
unnamed: D3.2 (A), R10.2
unnamed: D4.2 (A), R11.2
unnamed: F1.1, J3.A4 (VBUS), J3.A9 (VBUS), J3.B4 (VBUS), J3.B9 (VBUS)
unnamed: J3.A5 (CC1), R9.1
unnamed: J3.B5 (CC2), R8.1
unnamed: Q1.3 (C), Q2.1 (G), R7.1
unnamed: R1.2, U1.9 (RXD)
unnamed: R11.1, U1.6 (TNOW)
unnamed: C2.1, U1.10 (V3)
unnamed: R6.2, U1.4 (~RTS)
VBUS: C3.1, D2.1 (K), F1.2, Q1.2 (E), Q2.2 (S), R5.1, R10.1, U1.7 (VCC)
VCC: C1.1, J2.8, Q2.3 (D), R2.1, R3.1, R4.1, U2.8 (Vcc/AVcc/ADC_VRef+)

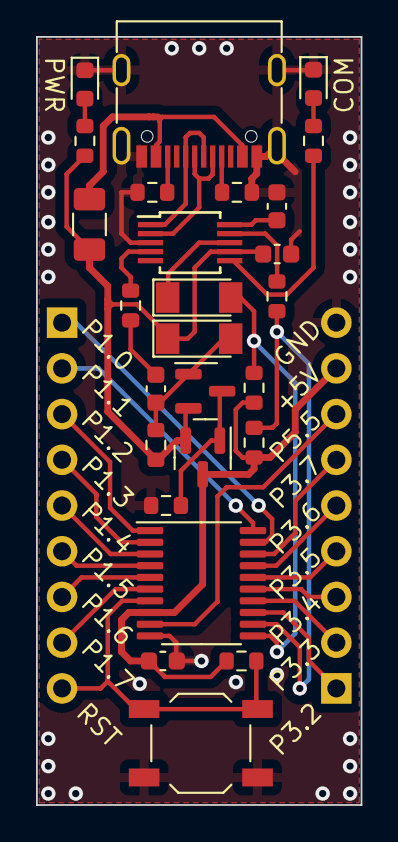
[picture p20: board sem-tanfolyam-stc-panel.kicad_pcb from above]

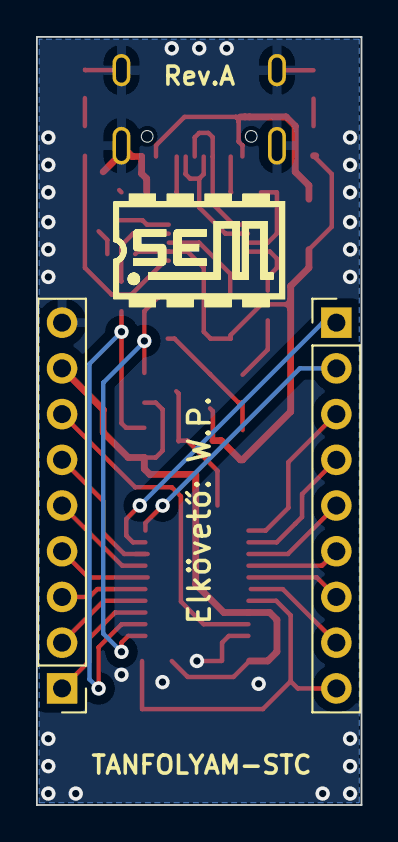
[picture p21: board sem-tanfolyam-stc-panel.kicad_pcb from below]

Board: 2 copper layers, 18.0 x 42.7 mm, 28 parts (2 on the bottom side), 36 nets.

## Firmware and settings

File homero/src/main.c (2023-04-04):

#include "fw_hal.h"
#include <math.h>

#define CLK    P15
#define DATA   P13
#define LATCH  P12

const uint8_t cau8SevenSegmentTableLeft[10] = 
{
    0x81,  // 0
    0xF9,  // 1
    0x43,  // 2
    0x61,  // 3
    0x39,  // 4
    0x25,  // 5
    0x05,  // 6
    0xF1,  // 7
    0x01,  // 8
    0x21   // 9
};

const uint8_t cau8SevenSegmentTableRight[10] = 
{
    0x18,  // 0
    0xF9,  // 1
    0x2C,  // 2
    0x68,  // 3
    0xC9,  // 4
    0x4A,  // 5
    0x0A,  // 6
    0xF8,  // 7
    0x08,  // 8
    0x48   // 9
};

void ShiftOut7Segment( uint16_t u16CodeWord )
{
    uint8_t u8Index;

    for( u8Index = 0; u8Index < 16; u8Index++ )
    {
        if( 0 != (u16CodeWord & ((uint16_t)1<<u8Index) ) )
        {
            DATA = 1;
        }
        else
        {
            DATA = 0;
        }
        SYS_DelayUs( 1 );
        CLK = 1;
        SYS_DelayUs( 1 );
        CLK = 0;
        SYS_DelayUs( 1 );
    }
    LATCH = 1;
    SYS_DelayUs( 1 );
    LATCH = 0;
}

int main( void )
{
    uint8_t __xdata u8Counter = 0;
    uint16_t u16Result;
    float    fTemp;

    // Init shift register pins
    GPIO_P1_SetMode( GPIO_Pin_2, GPIO_Mode_Output_PP );
    GPIO_P1_SetMode( GPIO_Pin_3, GPIO_Mode_Output_PP );
    GPIO_P1_SetMode( GPIO_Pin_5, GPIO_Mode_Output_PP );
    CLK = 0;
    LATCH = 0;

    // Init LED pins
    GPIO_P1_SetMode( GPIO_Pin_1, GPIO_Mode_Output_PP );  // right LED
    P11 = RESET;

    // Init ADC
    GPIO_P1_SetMode( GPIO_Pin_4, GPIO_Mode_Input_HIP );
    ADC_SetChannel( 4 );  // P1.4 is ADC channel 4
    // ADC Clock = SYSCLK / 2 / (1+prescaler)
    ADC_SetClockPrescaler( 15 );
    // Right alignment, high 2-bit in ADC_RES, low 8-bit in ADC_RESL
    ADC_SetResultAlignmentRight();
    // Turn on ADC power
    ADC_SetPowerState( HAL_State_ON );

    /*
    // Enable ADC interrupt
    EXTI_ADC_SetIntState(HAL_State_ON);
    // Globally enable interrupts
    EXTI_Global_SetIntState(HAL_State_ON);
    // Start conversion
    ADC_Start();
    */

    // Main loop
    while( 1 )
    {
        ADC_Start();  // start conversion
        NOP();
        NOP();
        while( !ADC_SamplingFinished() );
        ADC_ClearInterrupt();
        u16Result = ((uint16_t)ADC_RES<<8) | (uint16_t)ADC_RESL;

        fTemp = logf( ( 1024.0 / (float)u16Result ) - 1.0 ) / 3950.0 + 1.0/298.15;
        fTemp = 1.0/fTemp - 273.15;

        ShiftOut7Segment( (uint16_t)cau8SevenSegmentTableRight[ (uint8_t)floorf(fTemp+0.5)%10 ] | (uint16_t)cau8SevenSegmentTableLeft[ (uint8_t)floorf(fTemp+0.5)/10 ]<<8 );

        SYS_Delay(500);  // 100 ms delay
        P11 = !P11;
        u8Counter++;
        if( u8Counter >= 10 )
        {
            u8Counter = 0;
        }
    }
}

/*
INTERRUPT(ADC_Routine, EXTI_VectADC)
{
    uint16_t u16Result;
    float    fTemp;

    ADC_ClearInterrupt();

    u16Result = ((uint16_t)ADC_RES<<8) | (uint16_t)ADC_RESL;

    fTemp = logf( ( 1024.0 / (float)u16Result ) - 1.0 ) / 3950.0 + 1.0/298.15;
    fTemp = 1.0/fTemp - 273.15;

    ShiftOut7Segment( (uint16_t)cau8SevenSegmentTableRight[ (uint8_t)fTemp%10 ] | (uint16_t)cau8SevenSegmentTableLeft[ (uint8_t)fTemp/10 ]<<8 );

    // Restart ADC for continuous sampling
    ADC_Start();
}
*/

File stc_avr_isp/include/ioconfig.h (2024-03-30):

/************************
* STC8 series IO configuration
 * @Author  DT9025A
 * @Date    21/1/15
 * @License Apache License 2.0
 *
* This document is written based on STC8H documentation and can be adapted according to the target platform.
 ***********************/
#ifndef __STC8_IO_CONFIG_H__
#define __STC8_IO_CONFIG_H__

#include <fw_reg_stc8g.h>

#ifdef __STC8H_H_
#warning The default header file has not been changed, and the target platform is STC8H
#endif

//IO definition, add it when using it
#define PIN_0 0x01
#define PIN_1 0x02
#define PIN_2 0x04
#define PIN_3 0x08
#define PIN_4 0x10
#define PIN_5 0x20
#define PIN_6 0x40
#define PIN_7 0x80
#define PIN_ALL 0xFF

//Mode definition
#define PIN_MODE_STANDARD 0, 0
#define PIN_MODE_PUSHPULL 1, 0
#define PIN_MODE_HIRGRESIN 0, 1
#define PIN_MODE_OPENDRAIN 1, 1

//PULLUP status
#define PIN_PULLUP_ENABLE 1
#define PIN_PULLUP_DISABLE 0

//NCS status
#define PIN_NCS_ENABLE 0
#define PIN_NCS_DISABLE 1

//SR status
#define PIN_SWITCHRATE_HIGH 0
#define PIN_SWITCHRATE_LOW 1

//DR status
#define PIN_DRAINRATE_HIGH 0
#define PIN_DRAINRATE_LOW 1

//IE status
#define PIN_DIGITALSIGINPUTE_DISABLE 0
#define PIN_DIGITALSIGINPUTE_ENABLE 1

//IO mode
#define PIN_MODE_CONFIG(port, pin, mode) _PINMODE_CONFIG(port, pin, mode)
#define _PINMODE_CONFIG(port, pin, stat0, stat1)      \
    stat0 ? (port##M0 |= (pin)) : (port##M0 &= (~(pin))); \
    stat1 ? (port##M1 |= (pin)) : (port##M1 &= (~(pin)));

//Pull-up resistor setting
#define PIN_PULLUP_CONFIG(port, pin, stat) \
    (P_SW2 |= 0x80); \
    stat ? (port##PU |= (pin)) : (port##PU &= (~(pin))); \
    (P_SW2 &= ~0x80);

//Schmitt trigger setting, you need to set the highest position of P_SW2 to 1 before setting
#define PIN_NCS_CONFIG(port, pin, stat) \
    stat ? (port##NCS |= pin) : (port##NCS &= (~pin));

//Port conversion rate setting, you need to set the highest position of P_SW2 to 1 before setting
#define PIN_SWITCHRATE_CONFIG(port, pin, stat) \
    stat ? (port##SR |= pin) : (port##SR &= (~pin));

//Port drive current setting, you need to set the highest position of P_SW2 to 1 before setting
#define PIN_DRAINRATE_CONFIG(port, pin, stat) \
    stat ? (port##DR |= pin) : (port##DR &= (~pin));

//Digital signal enable setting, you need to set the highest position of P_SW2 to 1 before setting
#define PIN_DIGITALSIGINPUTENABLE_CONFIG(port, pin, stat) \
    stat ? (port##IE |= pin) : (port##IE &= (~pin));

#endif

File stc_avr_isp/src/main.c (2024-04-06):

/**
 *          STC8G1K08 AVRISP
 *
 *            License: BSD
 *
 *    STK500.c Referenced ArduinoISP.ino
 *   Copyright (c) 2008-2011 Randall Bohn
 *
 *        Modified by: DT9025A
 *           Date: 2021/2/9
 * ---------------------------------------
 *    Modified once more by: weiszpal
 *          Date: 2024/03/24
 * ---------------------------------------
 *
 * System clock = 12MHz
 * Reference: ArduinoISP.ino (44-52)
 *
 * UART rate selectable via P55: HIGH - 115200, LOW - 19200bps
 * Reference: ATMEL AVRISP User Guide (138) (https://community.atmel.com/sites/default/files/project_files/ATAVRISP_User_Guide.pdf)
 *
 * ---------------------------------------
 * 
 * P10 - PROGMODE LED
 * P11 - ERROR LED
 * P12 - RST
 * P13 - MOSI
 * P14 - MISO
 * P15 - SCK
 * P55 - UART RATE SELECT
 * 
 */

#include "stk500.h"
#include "uart.h"

INTERRUPT(Uart1_ISR, EXTI_VectUART1)
{
    if (RI) { //Receive data
        RI = 0; //Clear interrupt flag
        if (UART_RECV_PTR == UART_RECV_BUFFER_SIZE) //The queue is full
            UART_RECV_PTR = 0; //Reset the ring queue
        URAT_RECV_BUF[UART_RECV_PTR++] = SBUF; //Put in data
    }
}

void main()
{
    //Configure pin mode
    PIN_MODE_CONFIG(P1, PIN_2 | PIN_3 | PIN_4 | PIN_5, PIN_MODE_STANDARD); // SPI
    PIN_MODE_CONFIG(P1, PIN_0 | PIN_1, PIN_MODE_PUSHPULL); // LEDs

    for(unsigned char k=0; k<2; k++){
        P10 = 1;
        P11 = 0;
        delay(200);
        P10 = 0;
        P11 = 1;
        delay(200);
    }
    
    PIN_MODE_CONFIG(P5, PIN_5, PIN_MODE_HIRGRESIN);
    PIN_PULLUP_CONFIG(P5, PIN_5, PIN_PULLUP_ENABLE) // Baud selector JUMPER with pull-up

    Uart_Init(P55);

    EA = 1; //Enable global interrupt

    while (1) {
        P10 = ISP_PROGMODE;
        P11 = ((ISP_Error_Count>0) ? 1:0);
        if (Uart_Available()) {
            ISP_Process_Data(); //Process data
        }
    }
}

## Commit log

2023-02-08 Add core schematic (Rev A.1) and STC8G1K08 symbol
    [sem-tanfolyam-stc-panel.kicad_pcb, sem-tanfolyam-stc-panel.kicad_sch]
2023-02-10 Add peripherals to schematic and 7-segment display symbol and footprint
    [sem-tanfolyam-stc-panel.kicad_sch]
2023-02-23 Add PCB design
    [sem-tanfolyam-stc-panel.kicad_pcb, sem-tanfolyam-stc-panel.kicad_sch]
2023-02-23 Remove USER LED from schematic
    [sem-tanfolyam-stc-panel.kicad_sch]
2023-02-25 BOM hozzáadva + hiányosságok meggyógyítva.
    [sem-tanfolyam-stc-bom.xlsx, sem-tanfolyam-stc-panel.kicad_pcb, sem-tanfolyam-stc-panel.kicad_sch]
2023-02-25 Összemontírozva, gyártásra készen.
    [sem-tanfolyam-stc-panel.kicad_pcb, sem-tanfolyam-stc-panel.kicad_sch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]
2023-02-26 Final touches, PANELIZATION NEEDED
    [sem-tanfolyam-stc-panel.kicad_pcb, sem-tanfolyam-stc-panel.kicad_sch]
2023-02-26 Panelizálva és megrendelve.
    [montir_panel-top-pos.csv]
2023-02-27 Alappanel kapcsolási rajz hozzáadva
    [Tanfolyam_alappanel.kicad_pcb, Tanfolyam_alappanel.kicad_sch]
2023-03-23 Add single sided base board
    [Tanfolyam_alappanel.kicad_pcb, Tanfolyam_alappanel.kicad_sch]
2023-03-25 Changed 0805 footprints to 1206
    [Tanfolyam_alappanel.csv, Tanfolyam_alappanel.kicad_pcb, Tanfolyam_alappanel.kicad_sch]
2023-03-25 Gyártva a SEM-ben.
    [Tanfolyam_alappanel.kicad_pcb]
2024-02-25 Add 7-segment display 3D model and tutorial (demo) project for kicad8
    [SA39-11.STEP, Tanfolyam_alappanel.kicad_pcb, Tanfolyam_alappanel.kicad_sch]
2024-02-25 Demo projekt
    [Tanfolyam_alappanel.kicad_pcb, Tanfolyam_alappanel.kicad_sch]
2024-03-07 Add interactive BOM
2024-03-07 Add Interactive BOM with references placed correctly on silkscreen layer
    [Tanfolyam_alappanel.kicad_pcb]
2024-03-07 Interaktív BOM, már a FAB rétegek feliratai is jó helyen vannak
    [Tanfolyam_alappanel.kicad_pcb, Tanfolyam_alappanel.kicad_sch]
2024-03-30 Add AVR-ISP baseboard design with working firmware
    [hardware.kicad_pcb, hardware.kicad_sch, hardware_basic.kicad_pcb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]
2024-04-06 Add fancy blink animation on reset, specify resistor values
    [hardware.kicad_pcb, hardware.kicad_sch, hardware_basic.kicad_pcb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]
